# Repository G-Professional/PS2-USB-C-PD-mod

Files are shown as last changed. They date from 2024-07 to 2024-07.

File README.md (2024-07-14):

# PS2-USB-C-PD-mod

This is a USB-C power mod for the PS2 SCPH 50001

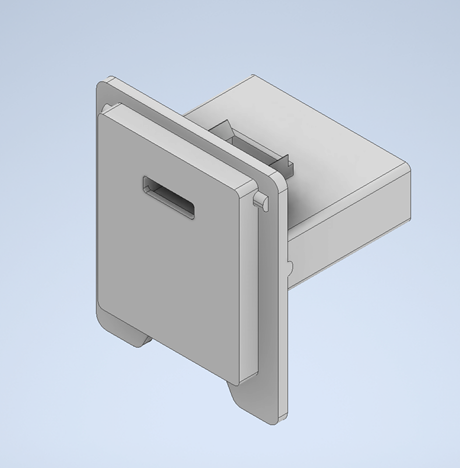
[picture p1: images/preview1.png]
sample


Parts:
  - Trigger board -
    - https://www.amazon.com/dp/B08LDJBN8P?ref=ppx_yo2ov_dt_b_product_details&th=1
   
Instructions:

*WARNING: This was designed for my specific needs. I did not check to see if this will work for every fat model PS2. I would not be surprised if other models/PSU use different voltages. Sending more voltage than a device needs will damage it!

First step is to short these 2 small middle pins on the trigger module. This will enable 12V. Check with a multimeter to ensure 12V +-.1V. If it is too low, the PS2 will not stay powered on. Too high and it will probably damage the PS2.

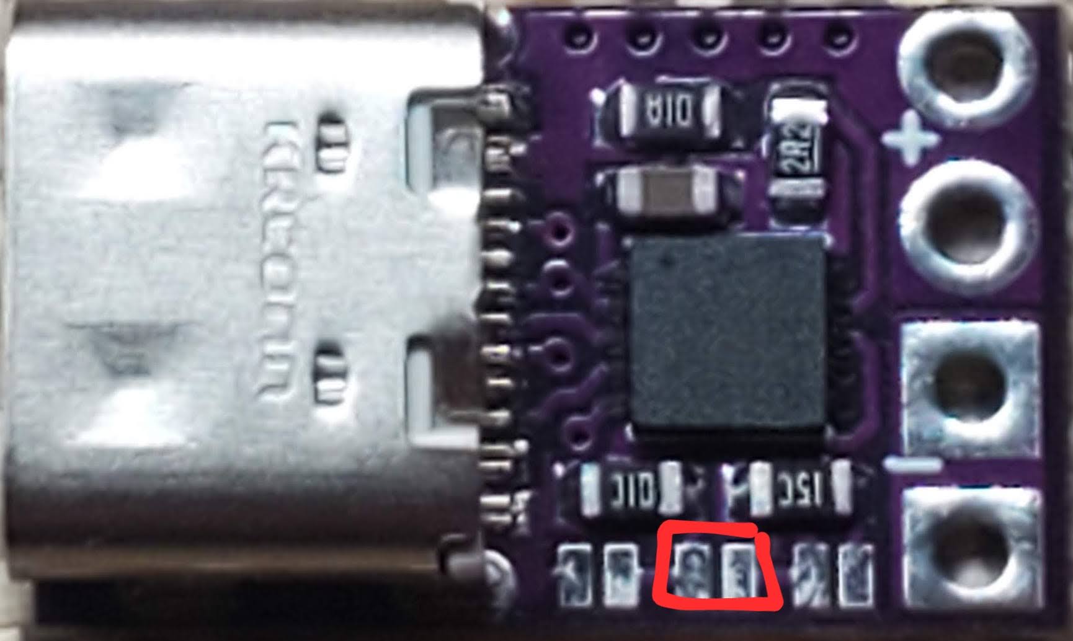
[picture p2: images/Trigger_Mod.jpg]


Next is to wire it to the connector.

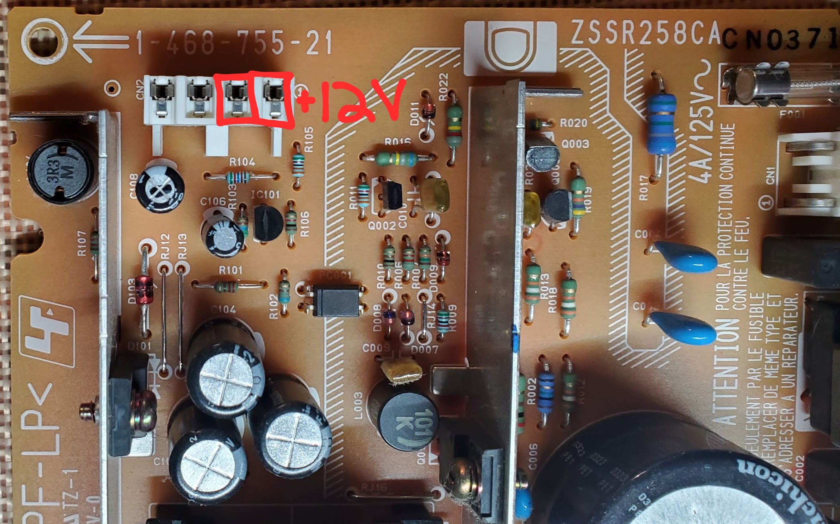
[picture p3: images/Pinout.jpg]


Next slot the module into the adapter, connect to the mobo. Double check orientation here, the connector is ambiguous.

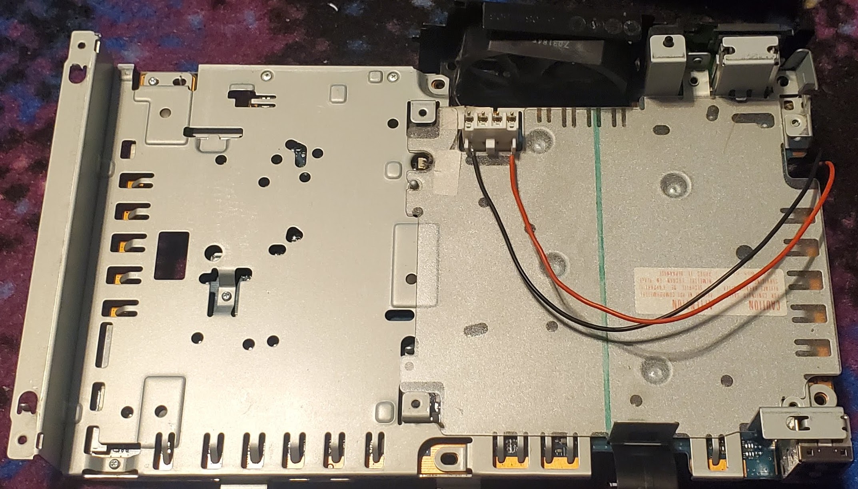
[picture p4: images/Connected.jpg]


The finished product.

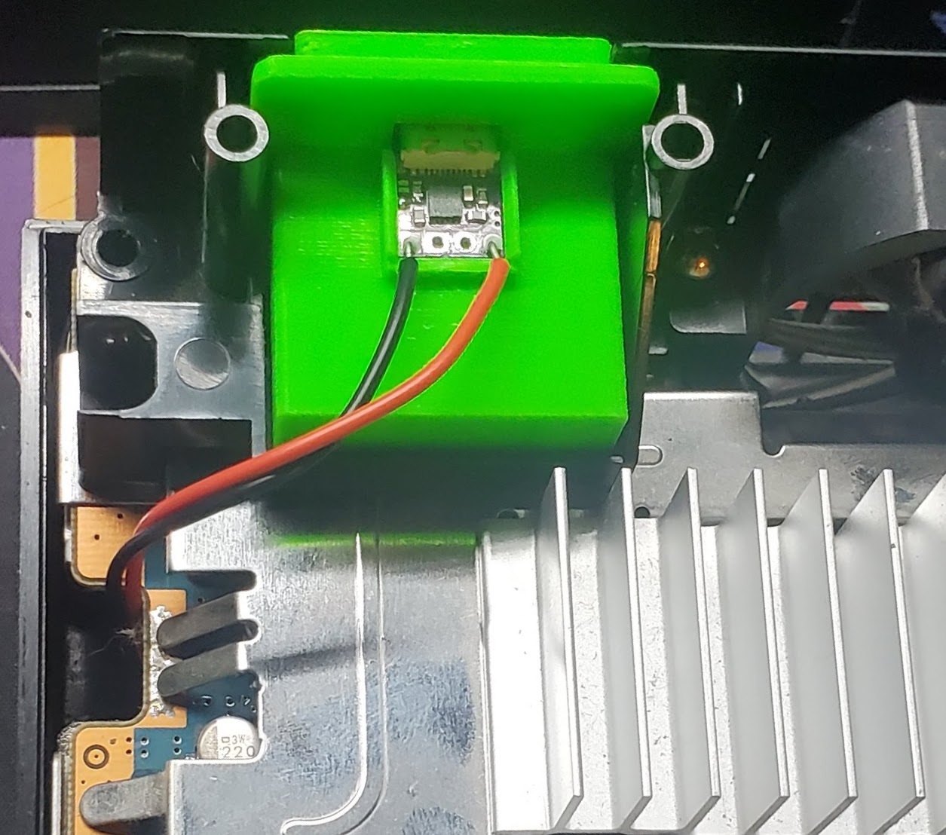
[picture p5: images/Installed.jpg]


Notes: 
  - output of stock PSU was 12.03V, triggerboard was 12.10V
  - personally, I dislike how incredibly tiny the trigger board is.
  - I wonder if there's a way to incorporate a power switch like stock.
  - With the final design, the fitment is very tight. I'm not actually sure if the trigger module can be removed with out damaging it.

Links:

https://cults3d.com/en/3d-model/tool/ps2-usb-c-pd-mount

 - USB C PD info
   - perhaps in the future I would like to design my own trigger board
   - https://resources.altium.com/p/add-usb-type-c-power-delivery-your-designs
   - https://octopart.com/search?q=cypd3177-24lqxq&currency=USD&specs=0
   - https://www.infineon.com/dgdl/Infineon-EZ-PD_BCR_Datasheet_USB_Type-C_Port_Controller_for_Power_Sinks-DataSheet-v03_00-EN.pdf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

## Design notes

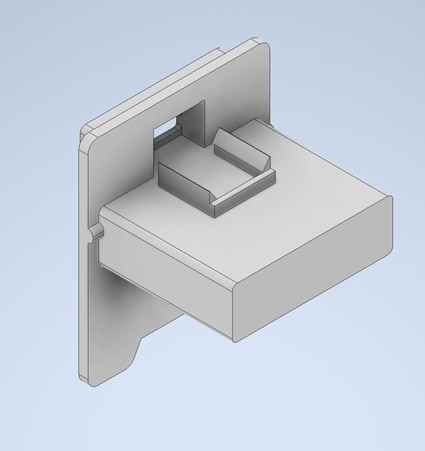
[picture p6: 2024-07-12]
images/preview2.png

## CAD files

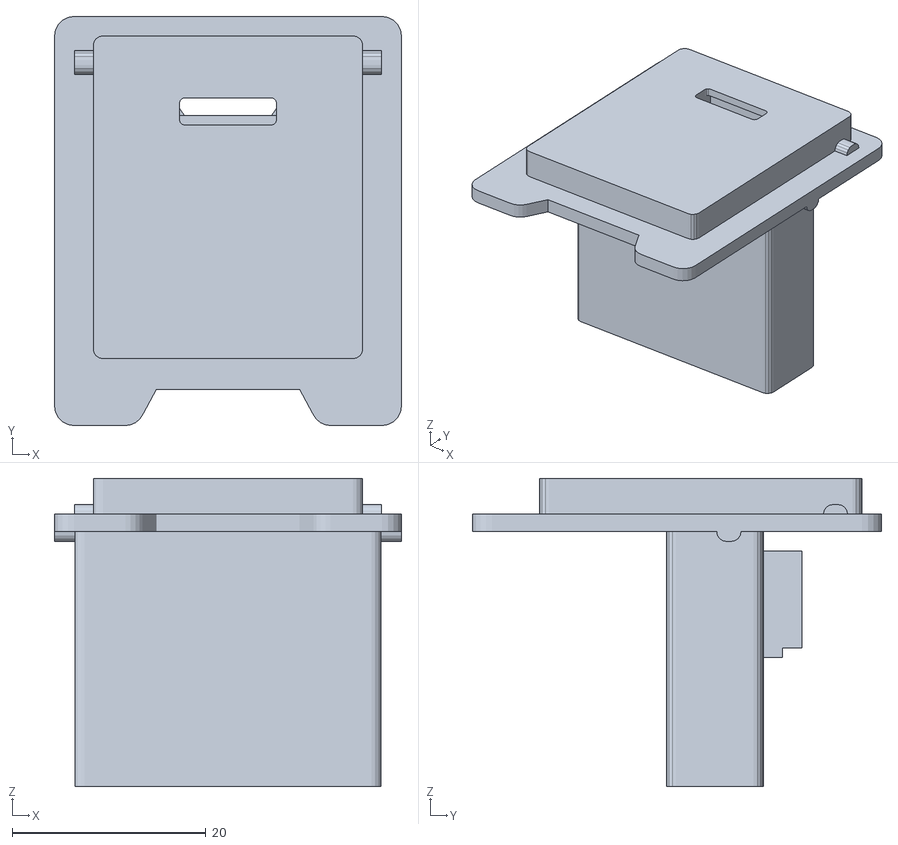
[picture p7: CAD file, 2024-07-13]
3dfiles/PS2 USB C PD Mount.stl
35.8 x 42.2 x 31.8

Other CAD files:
3dfiles/PS2 USB C PD Mount.ipt

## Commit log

2024-07-12 Rename PS2 USB C PD Mount.ipt to cad/PS2 USB C PD Mount.ipt
    [PS2 USB C PD Mount.ipt]
2024-07-13 Rename PS2 USB C PD Mount.ipt to 3dfiles/PS2 USB C PD Mount.ipt
    [PS2 USB C PD Mount.ipt]
2024-07-13 Rename PS2 USB C PD Mount.stl to 3dfiles/PS2 USB C PD Mount.stl
    [PS2 USB C PD Mount.stl]
